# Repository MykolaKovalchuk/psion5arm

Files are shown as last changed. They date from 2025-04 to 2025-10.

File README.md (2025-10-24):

# psion5arm
Psion Series 5 upgrade with ARM-based SBC

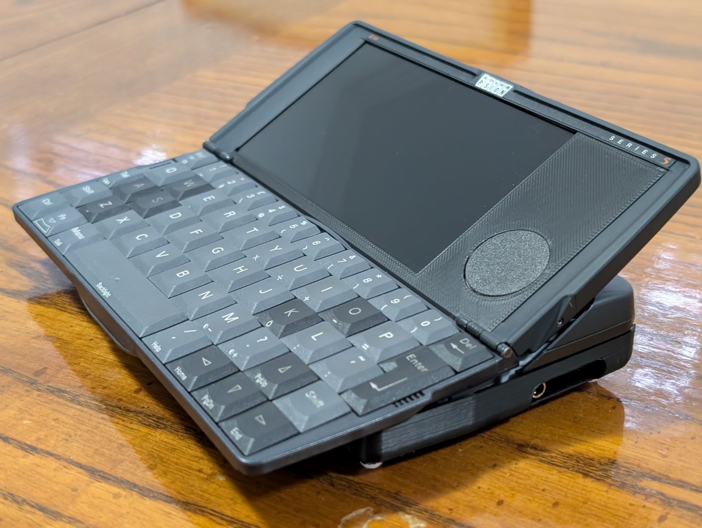
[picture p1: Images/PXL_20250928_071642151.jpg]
Modified Psion 5


Used components:
- Non-working Psion Series 5 for parts;
- New Single Board Computer : Khadas Edge2;
- Screen: Khadas TS050 - 5" full HD (1920x1080) touchscreen;
- Khadas Edge2 IO board - for internal USB for keyboard, SD card reader, and amplifier with speakers contacts;
- Cirque GlidePoint Circle Trackpad, 23mm version - small trackpad;
- Raspberry Pi Pico - keyboard and trackpad controller;
- Small power bank with 12V 2A power delivery - tested with two different 5,000mAh 22.5W power banks (output 5V3A, 9V2.22A, 12V1.67A, 10V2.25A, 22.5W Max), works at least without heavy load;

Folder [KeyboardWithMouse](/KeyboardWithMouse/) contains:
- Firmware for Raspberry Pico Pi to control Psion keyboard and Cirque trackpad;
- KiCad files for PCB to connect Raspberry Pi with keyboard and trackpad via 22-pin and 12-pin flat cables.
Code files for keyboard and trackpad (identified as mouse) contain links to original code, libraries, and guaide, which I have used to prepare my version of this controller.

Internal components (during testing):
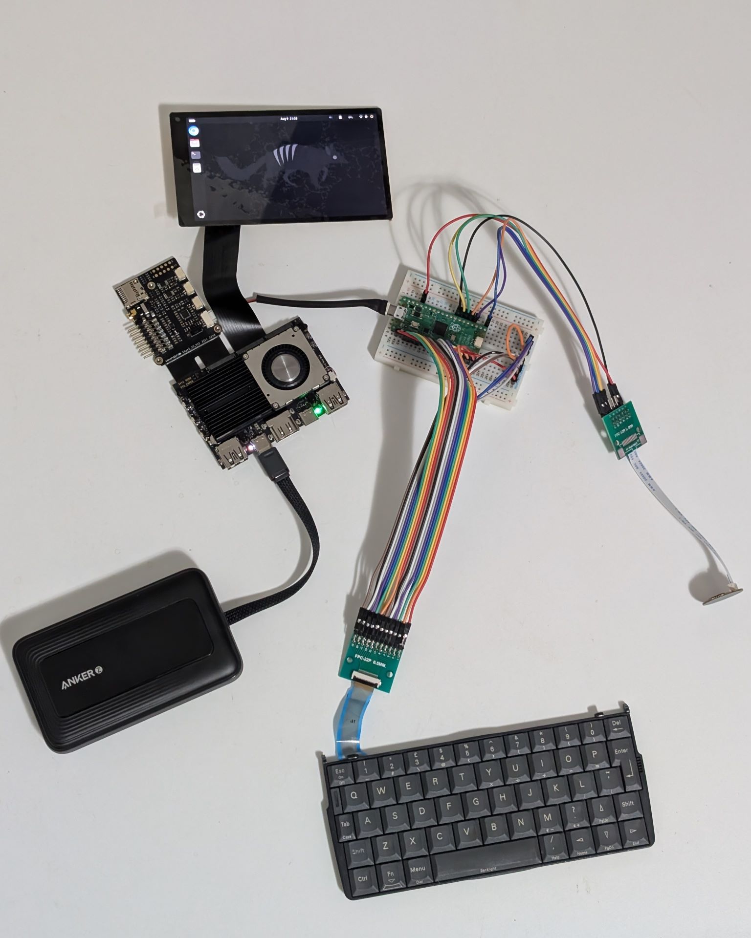
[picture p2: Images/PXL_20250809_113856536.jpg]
Internal Components


Components placement:
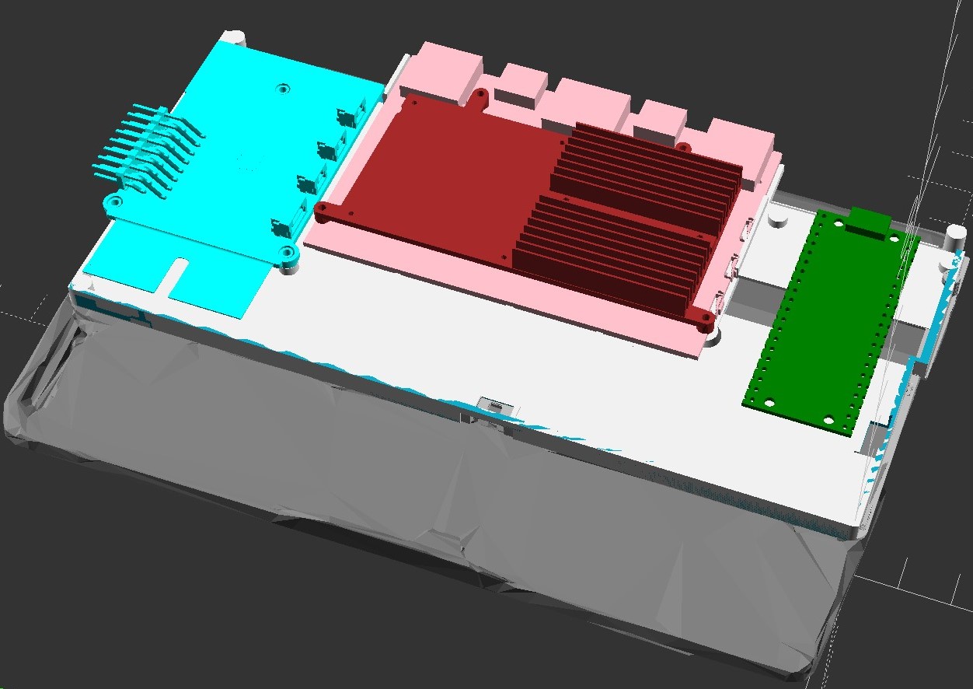
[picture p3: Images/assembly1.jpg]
Assembly 1

All components connected with lots of FPC flat cables and FPC extension boards (22pin for keyboard, 12pin for trackpad, 40pin for display+touchpad, 2 x 30pin for IO board).
Except Raspberry Pi connected to Khadas IO board via 4 wire USB interface (V, D+, D-, G).

Actual assembly:
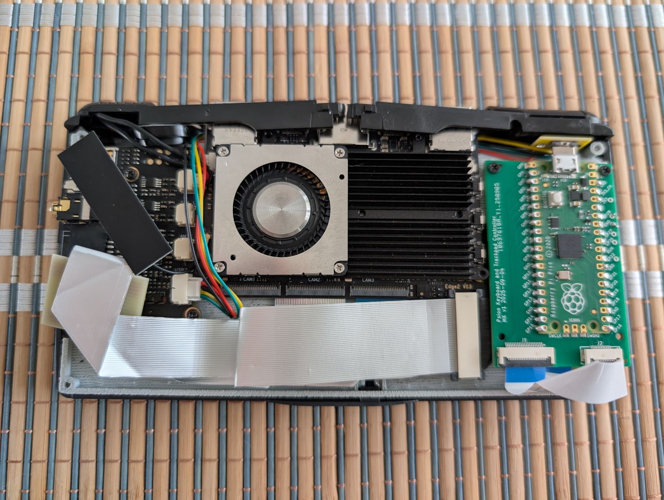
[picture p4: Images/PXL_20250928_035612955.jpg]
Assembly 2


3D models for new panels: https://www.printables.com/@MykolaKovalc_3575424/collections/2704362

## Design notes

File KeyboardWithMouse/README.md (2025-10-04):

# Combined driver for Psions Series 5 keyboard and Cirque trackpad

Firmware with combined driver for Psions Series 5 keyboard (connected with 22-pin FPC cable) and Cirque trackpad (connected with 12-pin FPC cable) for Raspberry Pico.

Code is written to use with Arduino IDE.
It needs Raspberry Pi Pico Arduino core from earlephilhower: https://github.com/earlephilhower/arduino-pico/ (using guide https://randomnerdtutorials.com/programming-raspberry-pi-pico-w-arduino-ide/).

Keyboard code based on original RasmusB code https://github.com/RasmusB/USB-Keyboard-Adapter and guide https://hackaday.io/project/4042-psio

Cirque Trackpad code is derived on library and examples from https://github.com/2bndy5/CirquePinnacle

Folder [PicoKMDriver](./PicoKMDriver/) contains firmware code.

Folder [PCB](./PCB/) contains KiCad scheme and pcb for a board to connect 22-pin FPC and 12-pin FPC to a Raspberry Pico and work with above firmware code.
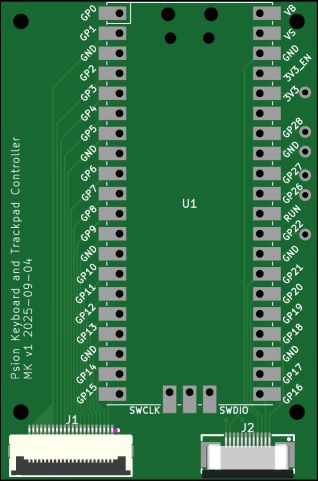
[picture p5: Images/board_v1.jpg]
PCB preview


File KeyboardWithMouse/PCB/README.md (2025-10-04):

# KiCad scheme and pcb for a board to connect 22-pin FPC and 12-pin FPC to a Raspberry Pico.

PCB preview

Footprint for Raspberry Pico are from https://github.com/ncarandini/KiCad-RP-Pico

Footprints for 22-pin and 12-pin FPC connectors were imported from JLCPCB for available suitable parts.

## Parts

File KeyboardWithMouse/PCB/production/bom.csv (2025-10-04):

Designator | Footprint | Quantity | Value | LCSC Part #
J1 | FPC-SMD_KH-FG0.5-H2.0-22PIN | 1 | Conn_01x22 | C2797212
J2 | FPC-SMD_KH-FG0.5-H2.0-12PIN | 1 | Conn_01x12 | C709366

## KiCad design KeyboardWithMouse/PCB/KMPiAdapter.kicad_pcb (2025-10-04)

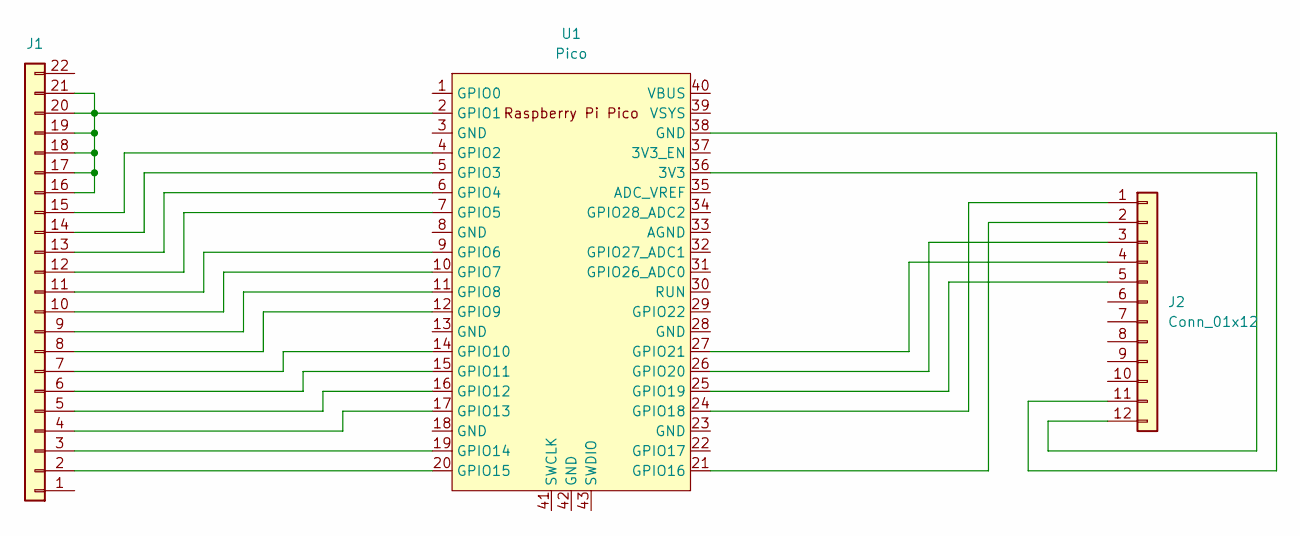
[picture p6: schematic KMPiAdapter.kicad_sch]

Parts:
J1: Conn_01x22; FPC-SMD_KH-FG0.5-H2.0-22PIN; LCSC Part # C2797212
J2: Conn_01x12; FPC-SMD_KH-FG0.5-H2.0-12PIN; LCSC Part # C709366
U1: Pico; RPi_Pico_SMD_TH

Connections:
unnamed: J1.2, U1.20 (GPIO15)
unnamed: J1.3, U1.19 (GPIO14)
unnamed: J1.4, U1.17 (GPIO13)
unnamed: J1.5, U1.16 (GPIO12)
unnamed: J1.6, U1.15 (GPIO11)
unnamed: J1.7, U1.14 (GPIO10)
unnamed: J1.8, U1.12 (GPIO9)
unnamed: J1.9, U1.11 (GPIO8)
unnamed: J1.10, U1.10 (GPIO7)
unnamed: J1.11, U1.9 (GPIO6)
unnamed: J1.12, U1.7 (GPIO5)
unnamed: J1.13, U1.6 (GPIO4)
unnamed: J1.14, U1.5 (GPIO3)
unnamed: J1.15, U1.4 (GPIO2)
unnamed: J1.16, J1.17, J1.18, J1.19, J1.20, J1.21, U1.2 (GPIO1)
unnamed: J2.1, U1.24 (GPIO18)
unnamed: J2.2, U1.21 (GPIO16)
unnamed: J2.3, U1.26 (GPIO20)
unnamed: J2.4, U1.27 (GPIO21)
unnamed: J2.5, U1.25 (GPIO19)
unnamed: J2.11, U1.38 (GND)
unnamed: J2.12, U1.36 (3V3)

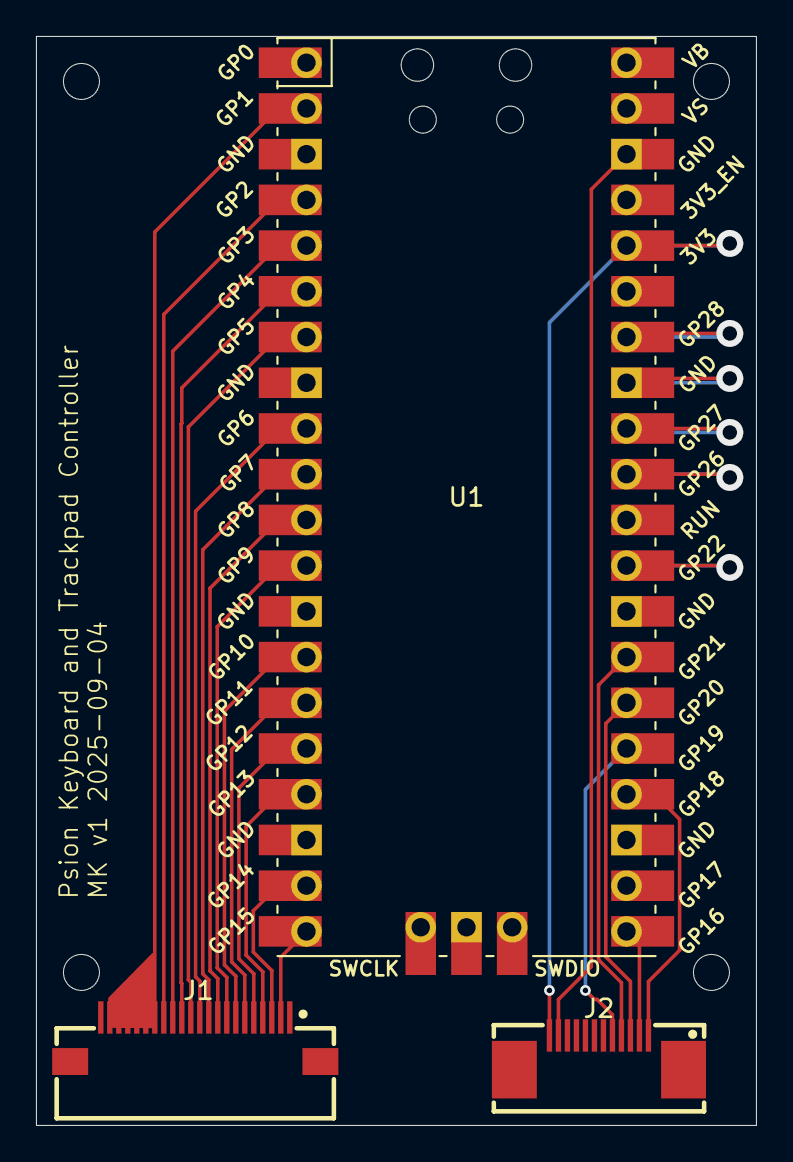
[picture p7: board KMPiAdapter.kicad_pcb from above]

Board: 2 copper layers, 40.0 x 60.5 mm, 3 parts (0 on the bottom side), 22 nets.

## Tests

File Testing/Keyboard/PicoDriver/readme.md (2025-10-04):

Program to test Psion keyboard only with Raspberry Pico.

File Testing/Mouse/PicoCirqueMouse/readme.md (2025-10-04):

Program to test Cirque trackpad as a mouse with Raspberry Pico.

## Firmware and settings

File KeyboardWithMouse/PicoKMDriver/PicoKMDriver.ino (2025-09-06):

/*
 Raspberry Pico USB keyboard driver for Psino Series 5 keyboard.
 Made in Arduino IDE with https://github.com/earlephilhower/arduino-pico/ library (using guide https://randomnerdtutorials.com/programming-raspberry-pi-pico-w-arduino-ide/).

 Keyboard code based on original RasmusB code https://github.com/RasmusB/USB-Keyboard-Adapter and guide https://hackaday.io/project/4042-psio
 Additional guide: https://jbmorley.co.uk/posts/2018-03-11-psion-bluetooth-keyboard/

 Cirque Trackpad code is derived on library and examples from https://github.com/2bndy5/CirquePinnacle
*/

#include <Keyboard.h>
#include <Mouse.h>
#include <CirquePinnacle.h>
#include "board.h"
#include "PsionKeymapUSB.h"

#define MAX_SCAN_RATE 1000 // Max number of scans/second

unsigned long previousTime;
unsigned int minDelay;

void setup()
{
  pinMode(LED, OUTPUT);
  digitalWrite(LED, HIGH);

  sleep_ms(1000);

  previousTime = 0;
  minDelay = 1000 / MAX_SCAN_RATE;

  setupKeyboard();
  setupTrackpad();

  digitalWrite(LED, LOW);
}

void loop()
{
  if ((millis() - previousTime) < minDelay)
  {
    delayMicroseconds(100);
    return;
  }

  processKeyboard();
  processTrackpad();

  previousTime = millis();
}

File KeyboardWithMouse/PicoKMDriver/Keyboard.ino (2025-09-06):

/*
 Keyboard code based on original RasmusB code https://github.com/RasmusB/USB-Keyboard-Adapter and guide https://hackaday.io/project/4042-psio
 Additional guide: https://jbmorley.co.uk/posts/2018-03-11-psion-bluetooth-keyboard/
*/

#define SWITCH_DELAY 50 // Microseconds to wait after setting output LOW before scannnig keys

int keypressArrayCurrent[NROWS][NCOLS];
int keypressArrayPrevious[NROWS][NCOLS];

bool fnPressed;
bool keyFModifierPressed; // Fn + F1_F10_Modifier + 1-0 = F1-F10

void setupKeyboard()
{
  Keyboard.begin();
  Keyboard.onLED(ledCB);

  for (int i = 0; i < NCOLS; i++)
  {
    pinMode(Cols[i], INPUT_PULLDOWN);
  }

  for (int i = 0; i < NROWS; i++)
  {
    pinMode(Rows[i], INPUT_PULLUP);
  }
}

void ledCB(bool numlock, bool capslock, bool scrolllock, bool compose, bool kana, void *cbData)
{
  (void) numlock;
  (void) scrolllock;
  (void) compose;
  (void) kana;
  (void) cbData;
  digitalWrite(LED, capslock ? HIGH : LOW);
}

void processKeyboard()
{
  int nKeysPressed = scanKeyboard(keypressArrayCurrent);

  sendKeys(keypressArrayCurrent, keypressArrayPrevious);
  if (nKeysPressed == 0)
  {
    Keyboard.releaseAll(); // Ensure we don't hold anything
  }

  // Remember which keys were pressed so we can release them later
  for (int col = 0; col < NCOLS; col++)
  {
    for (int row = 0; row < NROWS; row++)
    {
      if (keypressArrayPrevious[row][col] == 0 || keypressArrayCurrent[row][col] == 0) // Do not overwrite pressed keys with different scanCodes after Fn press or release
      {
        keypressArrayPrevious[row][col] = keypressArrayCurrent[row][col];
      }
    }
  }
}

int scanKeyboard(int keyArray[][NCOLS])
{
  int nKeysPressed = 0;
  fnPressed = false;
  keyFModifierPressed = false;

  // We need to go by columns first, because columns 7-12 combined on a single contact pin
  for (int col = 0; col < NCOLS; col++)
  {
    // Select a pin to sink current
    pinMode(Cols[col], OUTPUT);
    digitalWrite(Cols[col], LOW);
    delayMicroseconds(SWITCH_DELAY); // Without small delay there are some inconsistencies in keys scanning

    for (int row = 0; row < NROWS; row++)
    {
      int scanCode = keyScancode[row][col];

      if (scanCode != 0)
      {
        if (digitalRead(Rows[row]) == LOW)
        {
          if (keyArray[row][col] == 0) // If no pressed scancode yet stored
          {
            keyArray[row][col] = 1;
          }
          if (scanCode == KEY_FN)
          {
            fnPressed = true;
          }
          if (scanCode == KEY_F1_F10)
          {
            keyFModifierPressed = true;
          }

          nKeysPressed++;
        }
        else
        {
          keyArray[row][col] = 0;
        }
      }
    }

    pinMode(Cols[col], INPUT);
  }

  translateScanCodes(keyArray);

  return nKeysPressed;
}

void translateScanCodes(int keyArray[][NCOLS])
{
  for (int col = 0; col < NCOLS; col++)
  {
    for (int row = 0; row < NROWS; row++)
    {
      if (keyArray[row][col] == 1) // 1 == newly pressed key
      {
        int scanCode = keyScancode[row][col];
        if (fnPressed && keyFModifierPressed && scanCode >= KEY_0 && scanCode <= KEY_9) // Fn + F1_F10_Modifier + 1-0 = F1-F10
        {
          if (scanCode == KEY_0)
          {
            scanCode = KEY_F10;
          }
          else
          {
            scanCode = scanCode - KEY_1 + KEY_F1; // Translate 1-9 to F1-F9
          }
        }
        else if (fnPressed)
        {
          scanCode = keyFnScancode[row][col];
        }

        keyArray[row][col] = scanCode;
      }
    }
  }
}

void sendKeys(int pressedArray[][NCOLS], int previousArray[][NCOLS])
{
  bool mouseMoved = false;

  for (int row = 0; row < NROWS; row++)
  {
    for (int col = 0; col < NCOLS; col++)
    {
      int newKey = pressedArray[row][col];
      int oldKey = previousArray[row][col];

      if (newKey != KEY_FN && oldKey != KEY_FN) // Do not report Fn key itself
      {
        if (newKey != 0 && oldKey == 0) // If a new button is pressed (ignore key scanCode change by Fn press or release)
        {
          Keyboard.press(newKey);
        }
        else if (newKey == 0 && oldKey != 0) // This handles the release of keys
        {
          Keyboard.release(oldKey); // Release previously pressed key (with memory of its Fn state when pressed)
        }
      }
    }
  }
}

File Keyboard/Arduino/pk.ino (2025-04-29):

#include "board.h"
#include "Keyboard.h"
#include "PsionKeymapUSB.h"

#define KEYBOARD_ENABLED true

// Max number of scans/second
#define MAX_SCAN_RATE 100

int keypressArrayCurrent[NROWS][NCOLS];
int keypressArrayPrevious[NROWS][NCOLS];

unsigned long previousTime;
unsigned int minDelay;

void setup()
{
  previousTime = 0;
  minDelay = 1000 / MAX_SCAN_RATE;

  if (KEYBOARD_ENABLED) Keyboard.begin();

  pinMode(LED_BUILTIN, OUTPUT);

  for (int i = 0; i < NCOLS; i++)
  {
    pinMode(Cols[i], INPUT);
  }

  for (int i = 0; i < NROWS; i++)
  {
    pinMode(Rows[i], INPUT_PULLUP);
  }
}

void loop()
{
  if ((millis() - previousTime) >= minDelay)
  {
    // Scan the keyboard matrix
    int nKeysPressed = scanKeyboard(keypressArrayCurrent);

    //digitalWrite(LED_BUILTIN, keypressArrayCurrent[0][1]);
    digitalWrite(LED_BUILTIN, nKeysPressed == 0 ? LOW : HIGH);

    // Send the keypresses over USB
    if (KEYBOARD_ENABLED)
    {
      sendKeys(keypressArrayCurrent, keypressArrayPrevious);
    }

    // Remember which keys were pressed so we can release them later
    memcpy(keypressArrayPrevious, keypressArrayCurrent, sizeof(keypressArrayCurrent));
    previousTime = millis();
  }
}

int scanKeyboard(int keyArray[][NCOLS])
{
  int nKeysPressed = 0;

  for (int col = 0; col < NCOLS; col++)
  {
    // Select a pin to sink current
    pinMode(Cols[col], OUTPUT);
    digitalWrite(Cols[col], LOW);
    delay(1);

    for (int row = 0; row < NROWS; row++)
    {
      if (keyScancode[row][col] != 0)
      {
        if (digitalRead(Rows[row]) == LOW)
        {
          keyArray[row][col] = 1;
          nKeysPressed++;
        }
        else
        {
          keyArray[row][col] = 0;
        }
      }
    }

    pinMode(Cols[col], INPUT);
    //digitalWrite(Cols[col], LOW);
  }

  return nKeysPressed;
}

void sendKeys(int pressedArray[][NCOLS], int previousArray[][NCOLS])
{
  for (int row = 0; row < NROWS; row++)
  {
    for (int col = 0; col < NCOLS; col++)
    {
      // Only scan mapped buttons
      if (keyScancode[row][col] != 0)
      {
        // If a new button is pressed
        if (pressedArray[row][col] > previousArray[row][col])
        {
          Keyboard.press(keyScancode[row][col]);
        }
        // This handles the release of keys
        else if (pressedArray[row][col] < previousArray[row][col])
        {
          Keyboard.release(keyScancode[row][col]);
        }
      }
    }
  }
}

/*
void sendKeys(int pressedArray[][NCOLS], int previousArray[][NCOLS])
{
  for (int row = 0; row < NROWS; row++)
  {
    for (int col = 0; col < NCOLS; col++)
    {
      // Only scan mapped buttons
      if (keyScancode[row][col] != 0)
      {
        // If a new button is pressed
        if (pressedArray[row][col] > previousArray[row][col])
        {
          // Ugly hack to fix the Delete Key under Windows
          // Is the backspace key pressed?
          if ( row == 2 && col == 4)
          {
            // Is any of the shift keys pressed?
            if (pressedArray[0][6] > 0 || pressedArray[7][7] > 0)
            {
              // Shift is pressed, send DELETE
              Keyboard.press(KEY_DELETE);
            }
            else
            {
              // No Shift key pressed, send BACKSPACE
              Keyboard.press(KEY_BACKSPACE);
            }
          }
          else if ((row == 0 && col == 6) || (row == 7 && col == 7))
          {
            // Special handling of the SHIFT keys
            // Since we need to press SHIFT to send the KEY_DELETE, we need
            // to make sure that we don't send the shift key as well unless
            // BOTH shift keys are pressed...
            if (pressedArray[2][4] > 0)
            {
              // BACKSPACE/DELETE key is pressed
              if ((pressedArray[0][6] > 0) && (pressedArray[7][7] > 0))
              {
                // Both shift keys are pressed, send the SHIFT keys
                Keyboard.press(keyScancode[row][col]);
              } // If only one was pressed, we don't want to send SHIFT.
            }
            else {
              // Backspace / delete is not pressed
              // Send the shift keys as usual
              Keyboard.press(keyScancode[row][col]);
            }
          }
          else {
            // "Normal" keypress, just send as is
            Keyboard.press(keyScancode[row][col]);
          }
        }
        // This handles the release of keys
        else if (pressedArray[row][col] < previousArray[row][col])
        {
          // Make sure we release either BACKSPACE or DELETE; whatever was pressed
          if (row == 2 && col == 4)
          {
            Keyboard.release(KEY_DELETE);
            Keyboard.release(KEY_BACKSPACE);
          }
          else
          {
            Keyboard.release(keyScancode[row][col]);
          }
        }
      }
    }
  }
}
//*/

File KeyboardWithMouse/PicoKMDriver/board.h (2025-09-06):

/*
 This is how the pins are connected to the keyboard and trackpad.
*/

// This disables the RX and TX LEDs that are not on this PCB
#undef TXLED0
#undef RXLED0
#undef TXLED1
#undef RXLED1
#undef TX_RX_LED_INIT

#undef LED_BUILTIN_RX
#undef LED_BUILTIN_TX

#define TXLED0 0
#define RXLED0 0 
#define TXLED1 0
#define RXLED1 0
#define TX_RX_LED_INIT 0

#define LED_BUILTIN_RX 0
#define LED_BUILTIN_TX 0

#define LED 28 // Use GPIO 28 instead of LED_BUILTIN

// See the keyboard schematic for row/col mapping
#define NROWS 8
#define NCOLS 7

// Psion keyboard contacts numbered 1-22 left to right when looking on keyboard normally with contact cable placed straight up.
// Contacts 1 and 22 are not used.
// Use GPIO 1-15 - all on one side of RP2040 chip.

#define ROW_01  15 // 21
#define ROW_02  14 // 20
#define ROW_03  13 // 19
#define ROW_04  12 // 18
#define ROW_05  11 // 17
#define ROW_06  9  // 15
#define ROW_07  8  // 14
#define ROW_08  7  // 13

#define COL_1   10 // 16
#define COL_2   6  // 12
#define COL_3   5  // 11
#define COL_4   4  // 10
#define COL_5   3  // 9
#define COL_6   2  // 8
#define COL_7   1  // columns 7-12, contacts 2-7, combined together (each column contact just has 1 key mapped)

int Rows[NROWS] = {
  ROW_01,
  ROW_02,
  ROW_03,
  ROW_04,
  ROW_05,
  ROW_06,
  ROW_07,
  ROW_08
};

int Cols[NCOLS] = {
  COL_1,
  COL_2,
  COL_3,
  COL_4,
  COL_5,
  COL_6,
  COL_7
};

// Cirque trackpad connected with 12 contacts FPC cable (1-12), see https://github.com/2bndy5/CirquePinnacle
// Following Pico pins are used for Cirque contacts.
// Using SPI0 of Raspberry Pico.

// Contact 1  - SCK - pin 24 / GP18 / SPI0 SCK
// Contact 2  - SO  - pin 21 / GP16 / SPI0 RX
#define SS_PIN 20 // Contact 3  - SS  - pin 26 / GP20
#define DR_PIN 21 // Contact 4  - DR  - pin 27 / GP21
// Contact 5  - SI  - pin 25 / GP19 / SPI0 TX
// Contact 11 - GND - pin 28 / GND
// Contact 12 - VDD - pin 36 / 3V3(OUT)

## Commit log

2025-04-22 Initial RPi Pico project
2025-04-29 USB Keyboard for Pico in Arduino
2025-04-30 Clean keyboard driver files
2025-05-06 Delete .vscode/c_cpp_properties.json
    Keyboard driver was done in Arduino IDE, and VS Code settings for it are not needed.
2025-07-30 Combined keyboard and trackpad driver
2025-09-06 Use custom LED instead built in
2025-10-04 Control volume with brightness buttons
2025-10-04 PCB KiCad file with compiled production gerber files
    [KMPiAdapter.kicad_pcb, KMPiAdapter.kicad_sch, bom.csv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]
2025-10-04 Move test drivers to Testing folder
2025-10-04 Components and assembly
